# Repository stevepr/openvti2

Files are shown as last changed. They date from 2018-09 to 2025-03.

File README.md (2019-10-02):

# OpenVTI 2
----------------------------
The OpenVTI project implements a GPS based video time inserter for overlaying an accurate time stamp on each field of an analog video signal.  The OpenVTI device is an Arduino Mega 2560 single board computer along with a GPS receiver and a video overlay board.  This repository holds the Arduino source code.

## Building the OpenVTI software
---------------------------------
Prerequisites:
- Arduino IDE

## Building the OpenVTI hardware
------------------
The hardware:
- Arduino Mega 2560
- Gowoops GPS Module U-blox NEO-6M(Amazon: https://www.amazon.com/Gowoops-Module-Antenna-Arduino-Microcomputer/dp/B01MRNN3YZ)
- TinySine Video Overlay Shield using Max-7456

The source file pinconfig.h explains how to connect the GPS module and the TinySine board.

## Licensing
------------
 This program is free software: you can redistribute it and/or modify it under the terms of the GNU General Public License as published by the Free Software Foundation, either version 3 of the License, or (at your option) any later version.

 This program is distributed in the hope that it will be useful, but WITHOUT ANY WARRANTY; without even the implied warranty of MERCHANTABILITY or FITNESS FOR A PARTICULAR PURPOSE.  See the GNU General Public License for more details.

## Developers & Contributors
----------------------------
- Michael Fulbright
- Steve Preston

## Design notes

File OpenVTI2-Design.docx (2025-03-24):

# OpenVTI2 Design Document

Steve Preston (2025 Mar 24)

# 1 Overview

The OpenVTI project was initiated by Michael Fulbright in early 2017. The OpenVTI project provides both hardware guidelines and code for building a GPS based VTI (video time inserter) using an Arduino “platform”. This document describes OpenVTI2 - a “fork” in the design for the OpenVTI project.

The OpenVTI devices shared a single primary goal of overlaying an analog video signal with information which can be used to establish an accurate time, based on UTC (Coordinated Universal Time), for the VSYNC pulse at the start of each field in the analog video signal. In this sense, they are not different from the IOTA-VTI. The IOTA-VTI has a long history as an accurate, and successful VTI. The OpenVTI differs from the IOTA-VTI via simpler construction and, importantly, a simpler approach to the time stamp information. The IOTA-VTI is designed to both identify and correct many types of aberrant behaviors with the GPS receiver and the video signal. The OpenVTI is designed to merely detect and “flag” these errors (not correct the errors). In addition, the IOTA-VTI is a retail product that includes some level or service and support. And, the OpenVTI project is a DIY (Do It Yourself) effort with no support beyond the limited documentation provided with the code.

The OpenVTI2 design differs from the OpenVTI design in that it requires an Arduino Mega2560 instead of the less expensive Arduino Uno. In addition to the Arduino Mega2560, OpenVTI2 includes a GPS receiver “breakout board” based on a Ublox GPS receiver chip and an OSD (On Screen Display) Arduino shield based on the Max7456 video overlay chip.

# 2 Features

This section documents the three two basic features of OpenVTI2: The Video Overlay, the GPS serial data output, and the Error Checking.

## 2.1 Video Overlay

OpenVTI2 overlays two lines of information at the bottom of each video field: An Upper Line and a Lower Line. There are five display modes for the overlay: Time Valid, Waiting for GPS, Syncing, Error, and Fail. OpenVTI2 starts with the Invalid mode overlay and switches to the Valid mode display only after some initial error checking. After the initial startup, OpenVTI2 will switch to Invalid Mode after detecting any errors and only switch back to Valid mode after all errors have “cleared”. There is more information on error detection and error handling in another section of this document below.

### 2.1.1 Time Valid Overlay

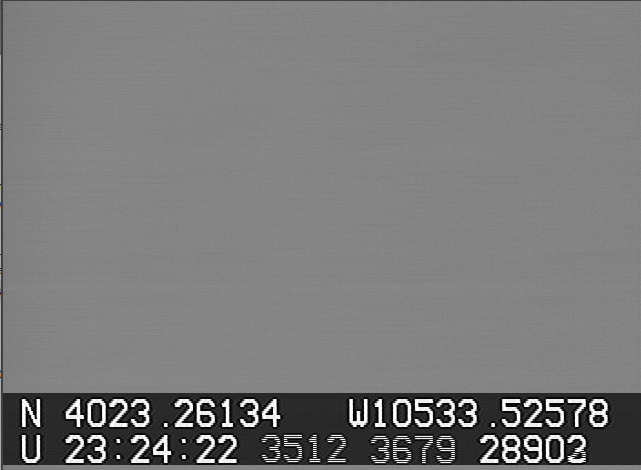
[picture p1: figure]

When OpenVTI2 has a valid time base it will use the Time Valid Overlay. In Time Valid mode, The Upper Line rotates through four different types of data type, changing data type once per second (at the arrival of the PPS signal from the GPS). Because the rotation of Upper Line data type occurs on a PPS and is not aligned with the arrival of the data sentences from the GPS receiver, some of these values may change during the one second interval for a data type. For example, the rotation for Lat/Long data may start with one value for Latitude and change to a different Latitude when it receives a new value from the GPS receiver prior to the end of the rotation period (next PPS).

- Date (UTC): This data type displays the date as DD-MM-YYYY
- Lat/Long: This data type displays the Latitude and Longitude.
- Altitude: This data type displays the MSL Altitude, units for the altitude, the geoid separation ( N ) , and the Datum for the Altitude.
- Version/UTC Offset: This data type displays a version number for the OpenVTI2 software and displays the current GPS-UTC time offset from the GPS Receiver. The UTC Offset value has a prefix of “D” when the GPS receiver is using the default value from the firmware. When the GPS receiver has acquired a new almanac (with a current UTC offset), there is no “D” postfix.

The Lower Line is divided into four “fixed” sections (no rotation):

- PPS Mark: Column 0 (first character) of the line will normally be blank but will change to a marker character during the first video field after a PPS from the GPS receiver.
- Time Base (G or U): Column 1 of the line will be “U” when the time displayed is UTC time and will be “G” when the time displayed is GPS time. OpenVTI2 displays GPS time when the GPS receiver is using the firmware default value for the GPS-UTC time offset.
- Time (HH:MM:SS) : Column 3 through 10 will be the HH:MM:SS part of the time stamp for the VSYNC at the beginning of the current video field.
- Field 1 Time: Column 12 through 15 are the fractional seconds of the time stamp for field 1. This section is blank during field 2.
- Field 2 Time: Column 17 through 20 are the fractional seconds of the time stamp for field 2. This section is blank during field 1.
- Field Count: Column 22 through 28 are the total number of VSYNC pulses that have been seen since power up of the OpenVTI2 device. This count resets to zero after 9999999.

### 2.1.2 Waiting for GPS Mode Overlay

After power-up, or after an error, OpenVTI2 will not have a valid time base and will start looking for valid data inputs from the GPS to begin synchronizing with the GPS time signals. During this timeframe OpenVTI2 will be in “Waiting for GPS” mode. In this mode, the video overlay will display an Upper Line and a Lower Line as follows.

The Upper Line has three data sections:

- Last PPS time: timer tick count of the last PPS pulse.
- Field 1 VSYNC time: When overlaying field 1 of the video signal, this section contains the OpenVTI2 timer tick count, in hex format, for the VSYNC at the start of field 1. Otherwise, this section is blank. This section starts with column 1.
- Field 2 VSYNC time: When overlaying field 2, this section contains the timer tick count for the VSYNC at the start of field 2. This section starts with column 15.

The Lower Line has two sections:

- Status Message: The message “Waiting for GPS” will appear starting in Column 1
- Field Count: Column 22 through 28 are the total number of VSYNC pulses that have been seen since power up of the OpenVTI2 device. This count resets to zero after 9999999.

### 2.1.3 Syncing Mode Overlay

After establishing valid GPS data communication (both NEMA sentences and PPS must be valid), OpenVTI2 will start the process of synchronizing the internal timer counts with the GPS inputs. This process should last approximate 5 seconds. In this mode, the video overlay will display an Upper Line and a Lower Line as follows.

The Upper Line has three data sections:

- Last PPS time: timer tick count of the last PPS pulse.
- Field 1 VSYNC time: When overlaying field 1 of the video signal, this section contains the OpenVTI2 timer tick count, in hex format, for the VSYNC at the start of field 1. Otherwise, this section is blank. This section starts with column 1.
- Field 2 VSYNC time: When overlaying field 2, this section contains the timer tick count for the VSYNC at the start of field 2. This section starts with column 15.

The Lower Line has two sections:

- Status Message: Starting in Column 1, the message “Sync” followed by the number of seconds remaining for the sync process.
- Field Count: Column 22 through 28 are the total number of VSYNC pulses that have been seen since power up of the OpenVTI2 device. This count resets to zero after 9999999.

### 2.1.4 Error Mode Overlay

OpenVTI2 enters Error mode if it detects a recoverable error during operation. In this mode, OpenVTI2 will display an error message for two seconds, then move to “Waiting for GPS” mode to try to re-establish a time base. In Error mode, the video overlay will display an Upper Line and a Lower Line as follows.

The Upper Line has three data sections:

- Last PPS time: timer tick count of the last PPS pulse.
- Field 1 VSYNC time: When overlaying field 1 of the video signal, this section contains the OpenVTI2 timer tick count, in hex format, for the VSYNC at the start of field 1. Otherwise, this section is blank. This section starts with column 1.
- Field 2 VSYNC time: When overlaying field 2, this section contains the timer tick count for the VSYNC at the start of field 2. This section starts with column 15.

The Lower Line has two sections:

- Status Message: Starting in Column 1, a message describing the error condition.
- Field Count: Column 22 through 28 are the total number of VSYNC pulses that have been seen since power up of the OpenVTI2 device. This count resets to zero after 9999999.

### 2.1.5 Failure Mode Overlay

OpenVTI2 enters Failure mode if it detects an Unrecoverable error during operation. In this mode, OpenVTI2 will display an error message on one line (the Lower line position). You must power cycle the device to exit Failure mode.

Currently, OpenVTI2 will enter failure mode only if it cannot initialize the GPS receiver.

## 2.2 GPS Serial Data Output

After power-up OpenVTI2 will output the GPS serial data stream (NMEA and PUBX sentences) to the Arduino’s USB port. The OpenVTI2 will send this data at a baud rate of 115200 baud. In addition to the NMEA and PUBX sentences, OpenVTI2 will also output a “time marker sentence” with 100 microseconds of the PPS signal from the GPS receiver and the VSYNC pulses on the video input signal. This following list describes the sentences output to the Arduino’s USB port.

- GPS Sentences: The GPS receiver outputs a stream of data sentences over the serial port to the Arduino. OpenVTI2 will echo these GPS sentences to the Arduino USB port one character at a time (as the characters are received from the GPS receiver). The following list is an example of the typical GPS sentences that will appear on the USB port.
  - $GPRMC
  - $GPGGA
  - $GPDTM
  - $PUBX,04 (proprietary sentence defined by Ublox. See the Ublox documentation for details)
- <P>TTTTTTTT</P>: marks the occurrence of the PPS signal from the GPS receiver. TTTTTTTT is the count from the internal timer of the Arduino (in hex format) at the time of the PPS. This output is sent as soon as possible after the occurrence of the PPS. Note: the internal timer is running at approximately 2mhz.
- <V>TTTTTTTT</V>: marks the occurrence of a VSYNC pulse in the video signal with the timer count for the VSYNC pulse. This output is sent as soon as possible after the occurrence of the VSYNC pulse.
- NOTE: the PPS and VSYNC outputs are send “immediately” from interrupt routines and may “interrupt” the output of a GPS sentence or a PPS/VSYNC output (thus appearing in the “middle” of another GPS sentence output to the USB port).

## 2.3 Error Checking

Perhaps “error checking” should be listed as a requirement rather than a feature, but this seemed like a reasonable part of the document to specify the error checks performed by the OpenVTI2 code.

The Arduino processor in OpenVTI2 examines inputs from two different sources to determine the timing of the input video signal: the GPS receiver and the Max7456 OSD chip. The GPS receiver provides basic time, position, and status information via sentences sent across a serial port connection to the Arduino. The GPS also outputs a “digital” PPS signal to the Arduino which marks the exact start of the UTC second. The Max7456 OSD chip outputs “digital” signals for both VSYNC and HSYNC pulses detected on the input analog video signal. The OpenVTI2 code performs validation checks on these inputs as described below.

### 2.3.1 Initialization of GPS Receiver

At power-up OpenVTI2 attempts to initialize the GPS receiver to a specific state by sending command across the serial port to the GPS receiver. The OpenVTI2 code expects an “ack” response to each initialization command sent to the GPS receiver. If the GPS receiver fails to send a valid “ack” response to any command, OpenVTI2 reports a “GPS Initialization failure” and enters Failure mode (non-recoverable error).

### 2.3.2 Validation of GPS Sentences

After receiving a full NMEA sentence from the GPS receiver, OpenVTI2 will parse the sentence to decode and validate the information in the sentence. OpenVTI2 checks various values for time and position. If OpenVTI2 finds an error when parsing a sentence, it will enter Error Mode, then move to “Waiting on Sync” to try to recapture synchronization with the GPS time base.

### 2.3.3 Validation of PPS signal from GPS Receiver

OpenVTI2 uses an internal timer, running at approximately 2mhz, on the Arduino processor as an internal time base. On each PPS signal from the GPS receiver, OpenVTI2 checks the delay from the previous PPS signal to ensure that the time between the two PPS signals was within a reasonable tolerance of a 1 second delay. If this test fails, OpenVTI2 enters Error Mode (to report the error), then moves to “Waiting on Sync” mode to begin the process of trying to recapture synchronization with the GPS time base.

OpenVTI2 also validates the correlation between the UT seconds reported in the NMEA sentences and the number of PPS signals received from the GPS receiver. The GPS receiver should send out a full set of NMEA sentences after every PPS signal. The NEMA data after each PPS signal provides the time of the preceding PPS signal. During the “Syncing” mode, OpenVTI2 will use the NMEA data to establish the time (in whole seconds) corresponding to each second. During Time Valid mode, after Syncing, OpenVTI2 will “know” the time corresponding to each PPS. At each NMEA time sentence, OpenVTI2 will verify the time from the latest NMEA sentence against the internal “PPS time”. If this test fails, OpenVTI2 will enter Error Mode (then attempts to re-sync).

### 2.3.4 Validating VSYNC input

The VSYNC signal is part of the video input and not actually used to establish the internal time base of OpenVTI2. However, the VSYNC signal generates an interrupt 50 or 60 times per second (NTSC or PAL video) and therefore provides a frequent opportunity to validate the timing of the PPS signal. At every VSYNC interrupt, OpenVTI2 checks the time delay since the last PPS signal. If the delay since the last PPS signal is significantly greater than 1 second, the GPS receiver has “missed” a PPS signal. If this error occurs, OpenVTI2 enters Error Mode (then attempts to re-sync).

# 3 Components/Build

OpenVTI2 comprises three main components: an Arduino Mega 2560 R3 board, a GPS receiver board based on a Ublox GPS receiver, and a Max7456 overlay “Arduino shield” from TinySine. Building the OpenVTI2 requires some additional pieces, and a small bit of soldering. This section provides more details on the parts and steps for building the OpenVTI.

Components/Build notes:

- Arduino Mega2560 R3
  - https://a.co/d/6sFUShn
- TinySine OSD shield
  - OSD Shield for Arduino - On Screen Display (https://www.tinyosshop.com/arduino-osd-shield)
  - Solder 1x3 or 1x4 Header for hsync/vsync/los jumper connection: Arduino Stackable Header(8Pin) (https://www.tinyosshop.com/index.php?route=product/product&path=63_80&product_id=80)
    - Cut this in half and use either a 4 pin and a 3 pin header
    - *** NOTE these headers have extra long pins. Order the 1x8 from TinySine to make sure the length matches the rest of the headers on the TinySine OSD board.
- OpenVTI Shield

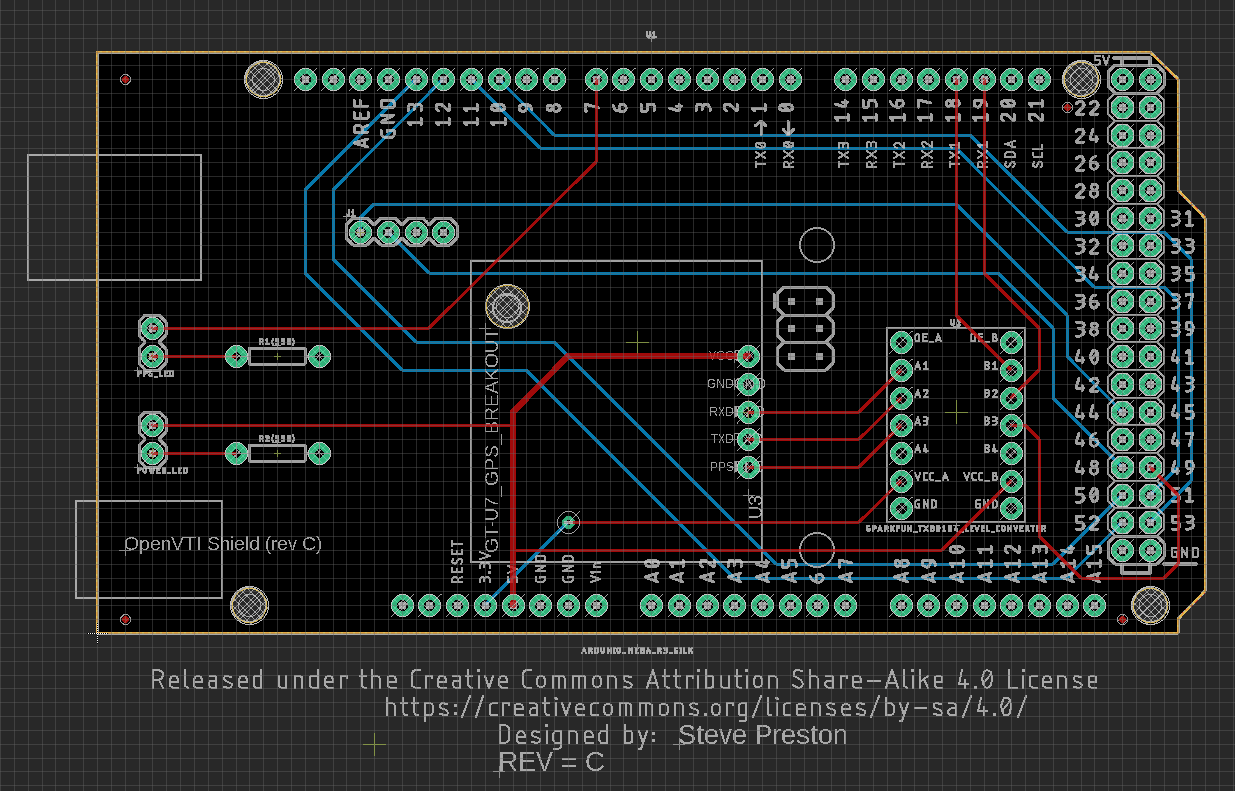
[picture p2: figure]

  - Order PCB using the Eagle file. I have always used OSHPark.
  - Solder Arduino Mega headers to the shield PCB
    - Header Kit from Amazon: https://a.co/d/1AGSMS7
  - Solder jumper for OSD connection
    - J1 (OSD) header - 1x4 female header. Note that a non-stacking female header is probably best.
  - Solder on LEDs
    - (2) Right angle: WP1533BQ/ID Kingbright | Optoelectronics | DigiKey (https://www.digikey.com/en/products/detail/kingbright/WP1533BQ-ID/2704754)
  - Breakout boards
    - Ublox GT-U7 GPS receiver: https://a.co/d/6Oyh4fR (2 pack)
      - Solder (1) 1x5 male header (GPS board usually includes this)
      - Solder breakout board to openVTI shield
      - Connect uFL to SMA cable to GPS board and anchor with a small zip tie
        - GPS Antenna + uFL to SMA cable https://a.co/d/1KBJGJA
    - TXB0104 level shifter: SparkFun Voltage-Level Translator Breakout - TXB0104 (https://www.sparkfun.com/sparkfun-voltage-level-translator-breakout-txb0104.html)
      - (2) 1x7 male headers. Probably best to add these headers to the txb0104 breakout before soldering onto the shield. Might help to have a "jig" for adding these headers to the breakout board.
      - Solder TXB0104 board to openVTI shield
  - Passive components
    - Solder (2) 330 ohm resistors to OpenVTI shield
- Final Assembly
  - Attach openVTI shield to Arduino Mega
  - Attach TinySine OSD shield on top of openVTI shield

Program

- Bring up the code with the Arduino IDE
- Set the Board type to Arduino Mega
- Set the Processor to AT Mega2560
- Set the Port (COMx)
- Sketch/Upload command to program the Arduino

# 4 Software Design Notes

## 4.1 Timing Strategy

OpenVTI2 uses the PPS signal from the GPS receiver as the only “time standard”. OpenVTI2 does NOT attempt to synchronize an internal timer with the PPS signal. Instead, OpenVTI2 validates PPS signals, tracks the HH:MM:SS time associated with each PPS, and generates a timestamp for each VSYNC of the video signal based on the delay from the most recent PPS signal.

OpenVT2 does use an internal timer to measure time delays: between occurrences of PPS and between a PPS and a VSYNC. The OpenVTI2 internal timer is set to a rate of approximately 2mhz. But OpenVTI2 constantly measures the average number of timer “ticks” for the interval between consecutive PPS signals and uses this value as the number of ticks/second for determining times.

## 4.2 Timer Config

OpenVTI2 uses two synchronized 16-bit timers.

## 4.3 General Interrupt configuration

The PPS and VSYNC inputs are key timing inputs to the system and both are connected to ICP inputs (input capture). The ICP input latches the time, timer count, of a signal within one processor clock cycle. A signal on the ICP line also generates an interrupt and transitions control to an ISR (Interrupt Service Routine) for the input signal. However, the ICP register avoids delays that can happen with when transitioning to an ISR (including delays due to other processing threads disabling interrupts). The ISR routine can read the ICP register to determine a very accurate time of the input signal regardless of the delay in transitioning to the ISR.

PPS is attached to the ICP register for Timer4 (ICP4) and VSYNC is attached to the ICP register for Timer5 (ICP5). These two timers are setup to be synchronized to the same exact time. Therefore ICP “times” for these two inputs are directly comparable.

Several internal variables are stored as “volatile”. Many of these variables are multi-byte quantities. When reading or writing a multi-byte volatile variable the code must be protected from interrupts. Otherwise an error might occur if an interrupt occurs while either reading or writing the variable.

## 4.4 Operating Modes (states)

There are six states for the device:

- Init – Startup and initialization of the GPS receiver and OSD board.
- WaitingForGPS – Waiting for valid PPS signals from the GPS receiver.
- Syncing – Synchronizing the internal second counts with the PPS and NMEA data from the GPS receiver.
- TimeValid – Current internal time is valid.
- Error – The device encountered and error and will try to restart.
- Fail – The device encountered an unrecoverable error.

## 4.5 PPS Interrupt Processing

The ISR routine for PPS interrupts has three primary purposes: validating the PPS signal, incrementing the HH:MM:SS second count for the current “system time”, and determining the main “state changes” in the system: from WaitingForGPS, to Syncing, to TimeValid. If this routine detects a PPS validation error during the Syncing or TimeValid mode, it transitions the system to ErrorMode.

## 4.6 VSYNC Interrupt Processing

The ISR routine for the VSYNC interrupt has one primary responsibility: updating the display. At each VSYNC, the ISR routine measure the time since the last PPS and updates the display. The information written to the display is dependent upon the current operating mode. In addition, the VSYNC ISR watches for missing PPS signals and moves to error mode if a PPS signal does not arrive in the expected timeframe.

## 4.7 Echo to USB port

OpenVTI2 echoes the NMEA sentences from the GPS receiver to the Arduino’s USB port. For these characters received over the serial port connected to the GPS receiver, OpenVTI2 echoes each character to the Arduino’s USB port as the character is received from the GPS receiver. OpenVT2 also sends a “marker” string to the USB port at each PPS from the GPS receiver. For the PPS markers, OpenVTI2 writes the PPS marker to the USB port from the PPS ISR. Similarly, OpenVTI2 sends a marker to the USB port for each VSYNC pulse (sent from the VSYNC ISR).

## 4.8 NMEA Parsing

OpenVTI2 reads the incoming serial port data from the GPS receiver via a polling loop in the system’s main process/routine. OpenVTI2 reads data from the serial port until it collects a single, complete NMEA sentence. After receiving a complete sentence, OpenVTI2 parses the data from the NMEA sentence and stores the data in an internal structure. After parsing a PUB04 sentence while in TimeValid mode, OpenVTI verifies that the HH:MM:SS fields from PUBX04 sentence matches the current internal HH:MM:SS count. If these values do not match, the system goes to Error Mode.

## 4.9 OSD Updates (Max7456 On Screen Display)

OpenVTI2 uses local memory arrays to store the data to be displayed in each row to overlay on the video signal. Both of the ISR routines and the main process loop may write data to these local memory arrays. But changes to the display will only update once per VSYNC pulse. At the end of each VSYNC ISR, OpenVTI2 writes the contents of the memory arrays to the Max7456 OSD chip.

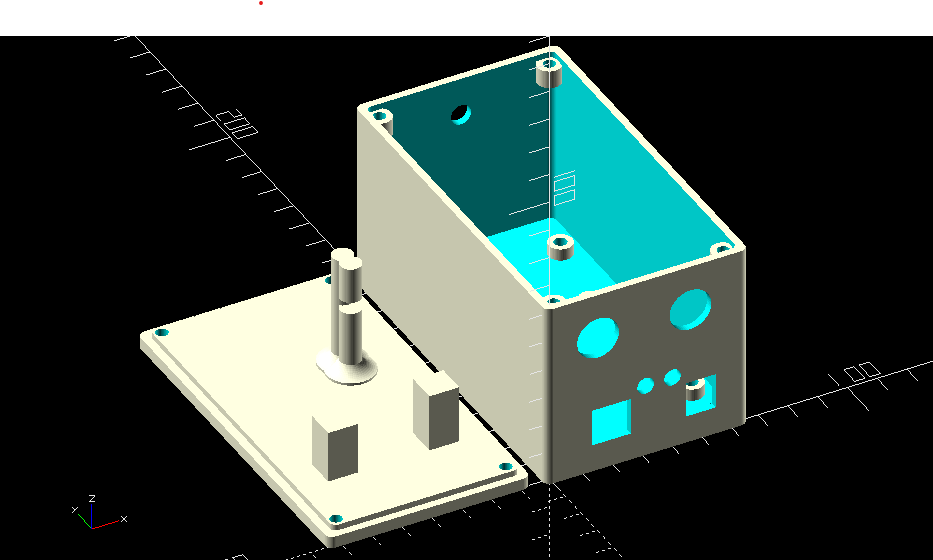
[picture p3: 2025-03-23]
enclosure/OpenVTI_Case_Image.png

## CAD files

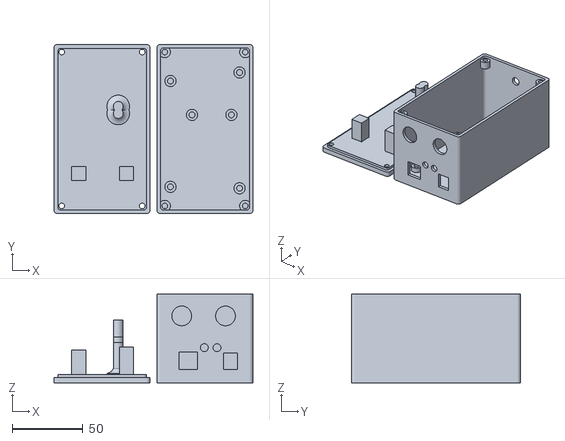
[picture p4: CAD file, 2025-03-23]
enclosure/Open_VTI_Case_Total.stl
141.0 x 120.0 x 63.0

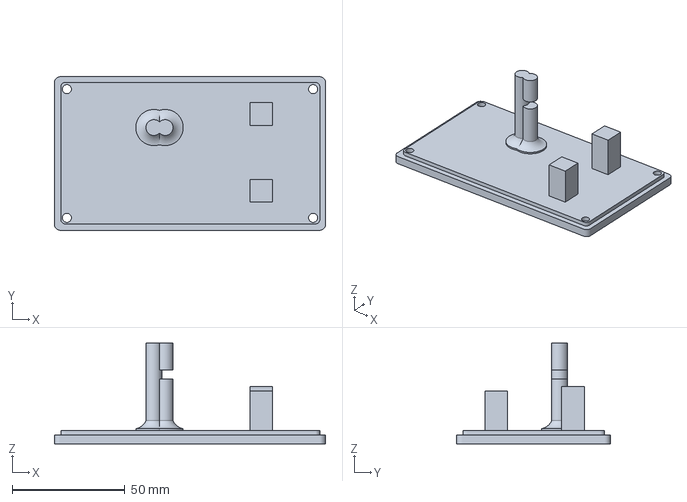
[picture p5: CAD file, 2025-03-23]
enclosure/Open_VTI_Case_lid_with_logo_qty_1.3mf
120.0 x 68.0 x 44.7 mm

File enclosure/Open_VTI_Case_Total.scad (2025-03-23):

//Mounting Pegs for Arduino Mega

// one complete peg

module peg(){

$fn=60;
    
difference(){
cylinder(7,d=8);
cylinder(8,d=4.2);
}

rotate_extrude()

    translate([2.5,0,0]){
    intersection(){
    square(5);
    difference(){
    square(5,true);
    translate([2.5,2.5])circle(2.5);    
            }  
        }
    }
}

module peg_placement(){

translate([2,16,0])
peg();

translate([2,91,0])
peg();

translate([51,15,0])
peg();

translate([51,97,0])
peg();

translate([17.3,67,0])
peg();
    
translate([45.2,67,0])
peg();

}

translate([5,0.5,0])
color("red")peg_placement();

$fn=60;
module case1(){
    minkowski(){
    cube([63,115,3]);
    cylinder(60,d=5);
    }
}

// Inner case for cutout

module case_inner(){
    minkowski(){
    cube([59,111,3]);
    cylinder(62,d=4);
    }
}

module case2(){
difference(){
case1();
translate([2,2,3])
color("blue")case_inner();
    }
}

//posts for lid

module case3(){
case2();
difference(){
translate([3,3,55])
color("red")cylinder(6,d=8);

translate([3,3,55])
color("green")cylinder(15,d=4);
}

difference(){
translate([3,112,55])
color("red")cylinder(6,d=8);

translate([3,112,55])
color("green")cylinder(15,d=4);
}

difference(){
translate([60,112,55])
color("red")cylinder(6,d=8);

translate([60,112,55])
color("green")cylinder(15,d=4);
}

difference(){
translate([60,3,55])
color("red")cylinder(6,d=8);

translate([60,3,55])
color("green")cylinder(15,d=4);
    }
}
// Lid

module lid1(){
translate([0,0,70]){
minkowski(){
    cube([63,115,2]);
    cylinder(2,d=5);
        }
    }
}
//translate([0,0,0])
//lid1();

module inner_lid(){
translate([2,2,68]){
minkowski(){
    cube([58.7,110.7,1]);
    cylinder(1,d=4);
        }
    }
}

//color("yellow")inner_lid();

module total_lid(){
    lid1();
    inner_lid();
}

module combined_lid(){
    lid1();
    inner_lid();
}

//punch holes in lid

module lid_with_holes(){
difference(){
combined_lid();

translate([3,3,63])
color("green")cylinder(15,d=4);

translate([3,112,63])
color("green")cylinder(15,d=4);

translate([60,112,63])
color("green")cylinder(15,d=4);

translate([60,3,63])
color("green")cylinder(15,d=4);
    }
}

translate([0,0,5])
rotate([0,180,0])

//lid with restraint

translate([10,0,-70])
lid_with_holes();

translate([-30,73.5,6.7])
color("blue")lid_restraint();

translate([-30,68.5,6.7])
color("blue")lid_restraint2();

module holes(){
//USB Hole
translate([16,-47,-0.6])
color("blue")cube([18,13,12.5
    ]);

//Power Hole
translate([16,-15.5,-0.6])
color("red")cube([19,10,12]);

//LED Holes
$fn=60;
rotate([0,90,0])
translate([-15,-29,15])
color("red")cylinder(20,d1=6,d2=5,true);

rotate([0,90,0])
translate([-15,-20,15])
color("red")cylinder(20,d1=6,d2=5,true);
    
    
//RCA Holes

rotate([0,90,0])
translate([-37.5,-45,10])
color("green")cylinder(30,d1=14,d2=14,true);

rotate([0,90,0])
translate([-37.5,-14,10])
color("green")cylinder(30,d1=14,d2=14,true);

// GPS SMA Hole

rotate([0,90,0])
translate([-40,-28,-99])
color("green")cylinder(10,d=6.8);

}

module case4(){
difference(){
case3();
translate([60,20,10])
rotate([0,0,270])
holes();
    }
}

case4();

// positioning nubs
/*
//right 
translate([57.6,88,1.8])
rotate([0,10,0])
color("red")cube([5,3,15]);

//left
translate([0.2,88,1.3])
rotate([0,-10,0])
color("red")cube([5,3,15]);

//rear

translate([29,101.6,2.3])
rotate([-10,0,0])
color("red")cube([3,13,16]);
*/
//clicker

module clicker(){
translate([0,0,-1])
cube([15,5,3],true);

rotate([10,0,0])
translate([-5,,0,8])
cube([5,2,20],true);

rotate([10,0,0])
translate([5,,0,8])
cube([5,2,20],true);


module click_stop(){

difference(){
translate([0,-4,12])
rotate([75,0,0])    
cube([15,8,4],true);
    
 translate([0,-4.6,9.3])
    rotate([10,0,0])
color("blue")cube([17,5,4],true);   

translate([0,0.4,15])
    rotate([12,0,0])
color("blue")cube([17,5,4],true);   
}
}
//translate([0,0,5])
//click_stop();
}

//translate([30.5,108,3])
//color("green")clicker();


// lid restraint


module lid_restraint(){

$fn=60;
    
cylinder(39,d=7);

rotate_extrude()

    translate([3,0,0]){
    intersection(){
    square(10);
    difference(){
    square(10,true);
    translate([6,7])circle(6);    
            }  
        }
    }
}

module lid_restraint2(){

$fn=60;

translate([0,0,27])
cylinder(12,d=7);
    
cylinder(23,d=7);

rotate_extrude()

    translate([3,0,0]){
    intersection(){
    square(10);
    difference(){
    square(10,true);
    translate([6,7])circle(6);    
            }  
        }
    }
}

translate([-29,21,6.5])
color("red")cube([10,10,20]);

translate([-63,21,6.5])
color("red")cube([10,10,18]);

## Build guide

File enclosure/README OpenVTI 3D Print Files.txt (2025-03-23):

OpenVTI 3D Print Files

File - OpenVTI_Case_Image.PNG - Case Image rendered using OpenSCAD
File - Open_VTI_Case_lid_with_logo_qty_1.3mf - File to print lid with logo
File - Open_VTI_Case_Total.scad - OpenSCAD case file
File - Open_VTI_Case_Total.stl - File to slice/print case 

Recommended filament - PETG.  Bambu Lab PETG-HF was used on BL X1-C printer
m3 brass inserts (7) - 3 for base (front left, front right, right rear), 4 for lid
m3 x 6mm screws (7)

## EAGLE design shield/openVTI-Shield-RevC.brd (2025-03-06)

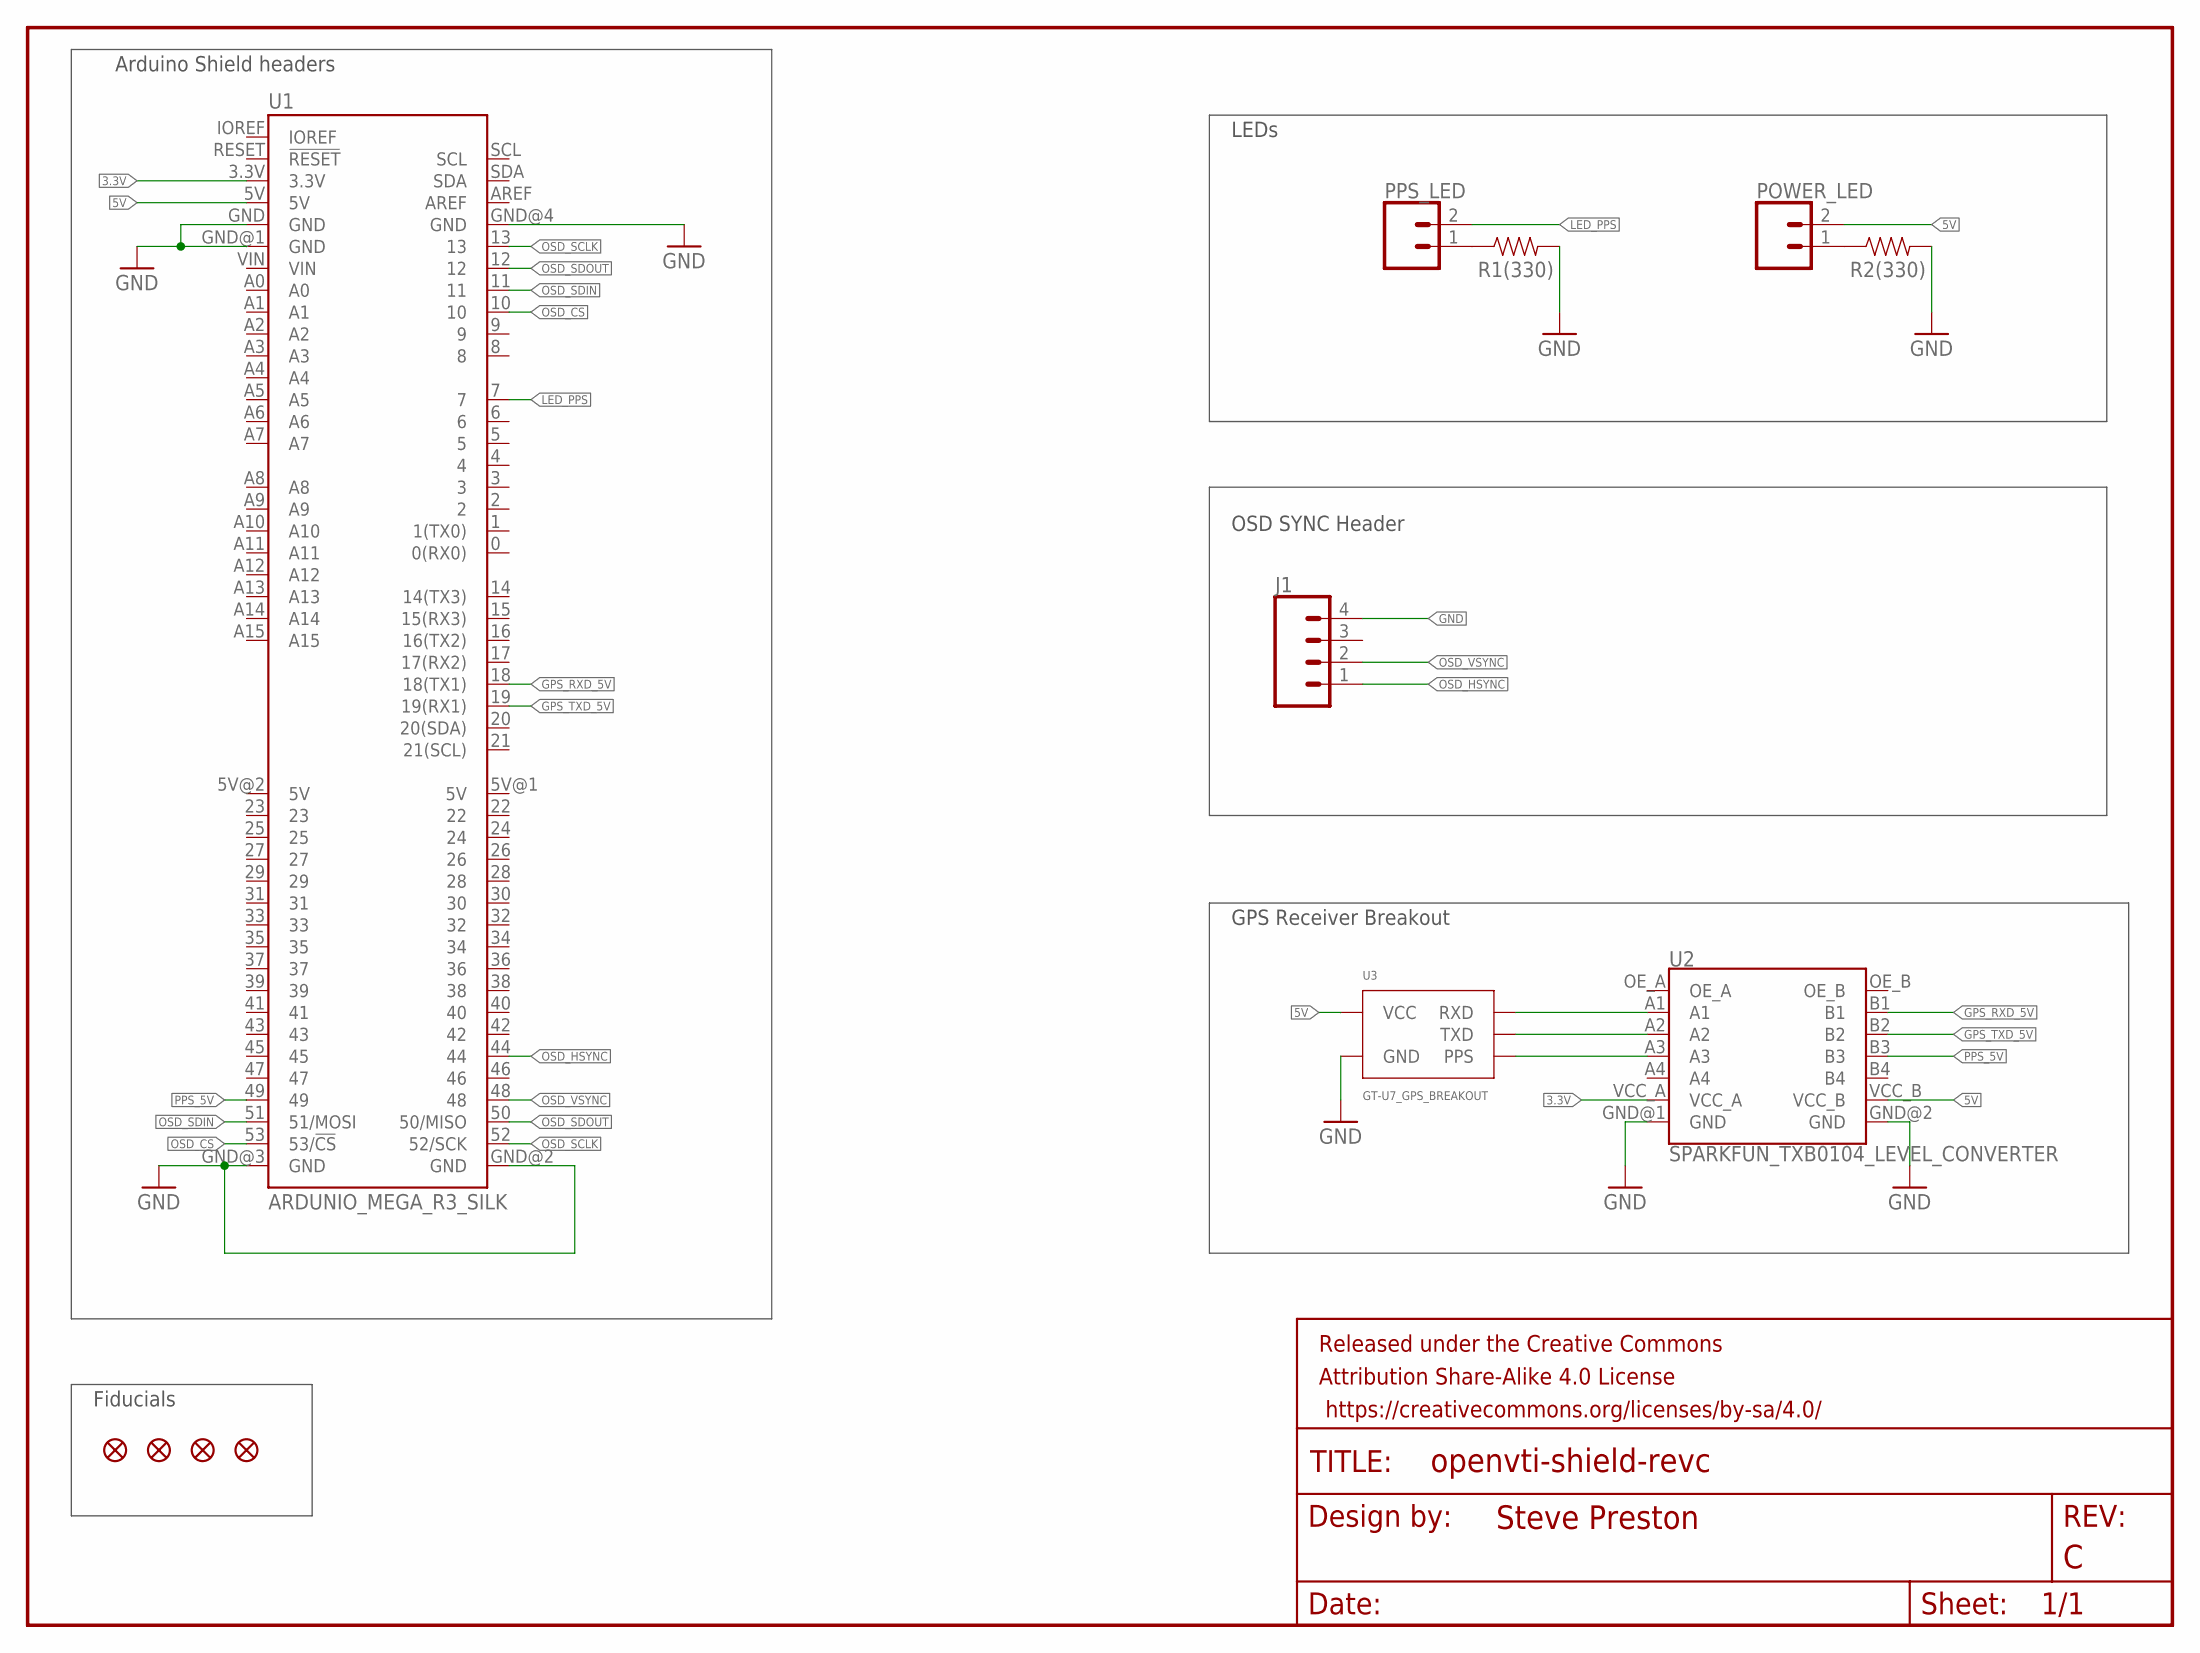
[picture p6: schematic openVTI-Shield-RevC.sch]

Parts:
FD1, FD2, FD3, FD4: FIDUCIALUFIDUCIAL; FIDUCIAL-MICRO
FRAME1: FRAME-LETTER; CREATIVE_COMMONS
J1: CONN_04PTH; 1X04
POWER_LED: CONN_02; 1X02
PPS_LED: CONN_02; 1X02
R1(330), R2(330): RESISTORAXIAL-0.3; AXIAL-0.3
U1: ARDUNIO_MEGA_R3_SILK; ARDUINO_MEGA_SILK
U2: SPARKFUN_TXB0104_LEVEL_CONVERTER; TXB0104_LEVEL_CONVERTER
U3: GT-U7_GPS_BREAKOUT; GT-UT

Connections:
3.3V: U1.3.3V, U2.VCC_A
5V: POWER_LED.2, U1.5V, U2.VCC_B, U3.VCC
GND: J1.4, R1(330).P$2 (2), R2(330).P$2 (2), U1.GND, U1.GND@1 (GND), U1.GND@2 (GND), U1.GND@3 (GND), U1.GND@4 (GND), U2.GND@1 (GND), U2.GND@2 (GND), U3.GND
GPS_RXD: U2.A1, U3.RXD
GPS_RXD_5V: U1.18 (18(TX1)), U2.B1
GPS_TXD: U2.A2, U3.TXD
GPS_TXD_5V: U1.19 (19(RX1)), U2.B2
LED_PPS: PPS_LED.2, U1.7
unnamed: PPS_LED.1, R1(330).P$1 (1)
unnamed: POWER_LED.1, R2(330).P$1 (1)
OSD_CS: U1.10, U1.53 (53/!CS)
OSD_HSYNC: J1.1, U1.44
OSD_SCLK: U1.13, U1.52 (52/SCK)
OSD_SDIN: U1.11, U1.51 (51/MOSI)
OSD_SDOUT: U1.12, U1.50 (50/MISO)
OSD_VSYNC: J1.2, U1.48
PPS: U2.A3, U3.PPS
PPS_5V: U1.49, U2.B3

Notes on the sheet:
LEDs
Arduino Shield headers
GPS Receiver Breakout
Fiducials
OSD SYNC Header

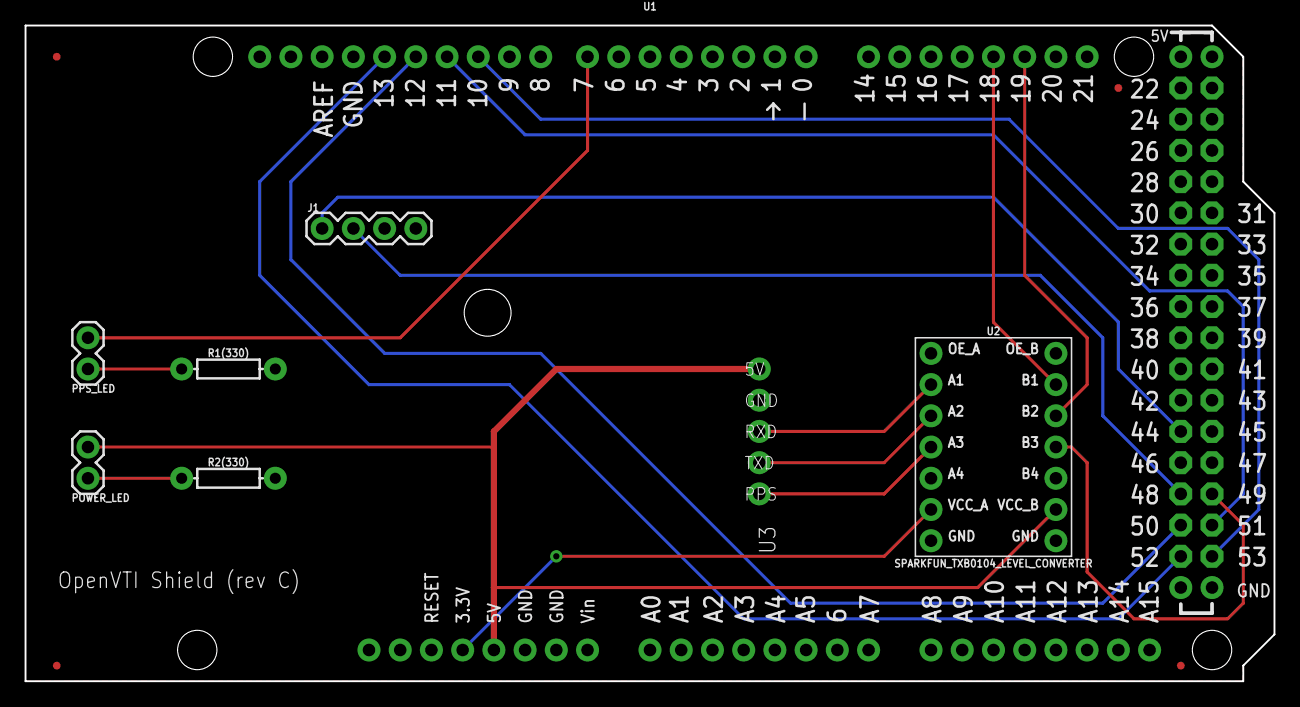
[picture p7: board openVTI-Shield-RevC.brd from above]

Board: 2 copper layers, 101.6 x 53.3 mm, 13 parts (0 on the bottom side), 18 nets.

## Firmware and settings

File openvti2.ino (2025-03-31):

/*

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
OpenVTI2

This is VERSION 6

ChangeLog

Version 1 
- initial using SoftwareSerial for GPS comms

Version 2 
- switch to HardwareSerial
- implemented field detection using VSYNC/HSYNC outputs from MAX7456 using external 555 or ATTINY13

Version 3
- use "arduino only" solution for field detection
- final version has working limovie time insertion

Version 4
- start with working limovie compatible time insertion
- move LED handler into VSYNC pin change interrupt handler
- make display more sparse to provide more area for stars!

Version 5
- SBP (from original OpenVTI code by MichaelF)
- interrupt driven PPS
- update OSD during vertical blanking
- write OSD update directly using auto-increment mode
- added code for parsing GPS serial data
- enabled  XXXX ublox proprietary sentence

Version 6
- moved to Mega2560 as required platform

VTI for following setup:

TinySine Video Overlay using Max-7456
Gowoops GPS Module U-blox NEO-6M
  (Amazon: https://www.amazon.com/Gowoops-Module-Antenna-Arduino-Microcomputer/dp/B01MRNN3YZ)

Use 5V power for GPS.

Use level converter for GPS signals to Arduino (TX,RX, and PPS)

Configure ublox GPS to the following:

- output GPGGA and PUBX,04 NMEA messages
- Timepulse set to UTC time (defaults to GPS)


LIBRARY NOTES:

I decided to start including library files in sketch directory - this way I can keep it self contained

MAX7456

I included zip files as well for original library
      
*/

// Included Libraries //////////////////////////////////////////////////////////

#include "pinconfig.h"
#include <SPI.h>
#include "MAX7456.h"
#include <util/crc16.h>

//  Global Settings ///////////////////////////////////////////////////////////////
#define VERSION  6

#define GRAYBACKGROUND 1    // == 1 => set gray background behind OSD lines
                            // == 0 => transparent background behind OSD lines


#define TESTROW 0           // == 1 => enable third row at top of display for testing/debug
                            // == 0 =>  no third row...

// Global Constants & Variables ////////////////////////////////////////////////////////////
//

// CRC data
//
uint32_t ProgramLength = 0x3000;
uint16_t pgmCRC = 0;

//*********************************
//  General state info
//
enum CountSource
{
  CNT4,
  CNT5,
  CR4,
  CR5
};

// Operating Modes
//
enum OperatingMode
{
  InitMode,               // => Power up initialization
  WaitingForGPS,          // => Waiting to receive valid GPS data
  Syncing,                // => Synchronizing internal time base with GPS data
  TimeValid,              // => Time is valid  (nominal operating mode for time insertion)
  ErrorMode,              // => Error was found
  FailMode                // => Unrecoverable failure found
};
volatile OperatingMode CurrentMode;    // Current operating mode
bool blnVideoIn = false;              // true iff video signal on input line
int errVideo = 0;


#define SYNC_SECONDS 10                // # of seconds for syncing to GPS time
volatile short int TimeSync;          // ( > 0 ) => we are syncing to GPS sentence times = # of seconds remaining for sync (small value so no problem with ints)

volatile int ErrorCountdown;
#define ERROR_DISPLAY_SECONDS 2

// Version message
//
char msgVersion[] = "6.4";
#define len_msgVersion 4

// Error Messsages
//
char msgGPSfail[] ="GPS init failed";
#define len_msgGPSfail  15
char msgWaiting[] = "Waiting for GPS";
#define len_msgWaiting  15
char msgSync[] = "Sync ";         // space for remainder
#define len_msgSync  4
char msgNoPPS[] = "*PPS ERROR*";
#define len_msgNoPPS 11
char msgSyncFailed[] = "*Sync FAILED*";
#define len_msgSyncFailed 13
char msgUnknownError[] = "*FATAL ERROR*";
#define len_msgUnknownError 13
char msgNoVSYNC[] = "*No VSYNC*";
#define len_msgNoVSYNC 13

char msgErrorCodes[] = "   ";
#define len_msgErrorCodes 3

// Sync Errors
//  1 = neither RMC nor PUBX04 is good
//  2 = RMC seconds does not match internal time
//  3 = RMC mode delay is neither A nor D
//  4 = RMC time delay != PPS time
//  5 = PUBX04 time != PPS time
//  6 = error transitioning from GPS time to UTC time


// Command string from the PC
//
#define CommandSize 30            // max size of a command string 
char strCommand[ CommandSize + 1 ];
int Cmd_Next;                     // speed optimization ( -1 => full command pending )

//***************
// OSD info
//
volatile bool EnableOverlay = false;      // update Overlay?
volatile bool blnSingleLineTest = false;  // true => display Bottom line ONLY in the TOP position (to allow another time stamp below).

// OSD object
//
MAX7456 OSD( osdChipSelect );

//  Local OSD rows
//
uint8_t TopRow[30];

uint8_t BottomRow[30];

#if (TESTROW == 1)
uint8_t TestRow[30];
#endif

// location of UI elements
//
#define TOP_ROW_NTSC 11
#define BOTTOM_ROW_NTSC  12
#define TOP_ROW_PAL 14
#define BOTTOM_ROW_PAL 15

#define FIELD1TS_COL 12
#define FIELD1TS_ROW BOTTOM_ROW

#define FIELD2TS_COL 17
#define FIELD2TS_ROW BOTTOM_ROW

#define FIELDTOT_COL 22
#define FIELDTOT_ROW BOTTOM_ROW
#define FIELDTOT_MAX 9999999        // max field count (row is only 29 char wide reliably)

volatile int osdTop_RowOffset = TOP_ROW_NTSC*30;   // display memory offset to start of ROW for cycling through data
volatile int osdTop_Col = 1;                       // starting colum in this ROW

volatile int osdBottom_RowOffset = BOTTOM_ROW_NTSC*30;   // display memory offset to start of ROW for time data
volatile int osdBottom_Col = 1;

// pixel offset of display to Match IOTA-VTI
//
#define OSD_X_OFFSET  0
#define OSD_Y_OFFSET  0

//
// Video input info
//
uint8_t videoStd;     // NTSC or PAL setting

volatile unsigned long fieldTotal;      // total number of fields (VSYNC pulses encountered)

volatile int fieldParity = 0;           // 1=> field 1, 2=> field 2  (0 => not yet set)

volatile unsigned long tk_VSYNC;      // vsync "time" = 2mhz ticks
volatile unsigned long tk_HSYNC;      // hsync "time" = 2mhz ticks

volatile unsigned short osdRotation = 0;             // rotation counter for top row (uses only one byte of short so we don't have to worry about interrupts)

//***********************
//  Time
//
volatile unsigned short timer4_ov;                            // timer 4 overflow count = high word of "time" (32ms per overflow)
volatile unsigned long Timer_Second = 2000000;                // # of ticks for 1 second
volatile unsigned long Timer_100ms = 200000;                  // ticks / 100ms
volatile unsigned long PPS_TOLERANCE = 2000;                  // tolerance for PPS interval - 1ms
volatile unsigned long CLOCK_TOLERANCE = 20000;               // tolerance for arduino clock frequency interval - currently 10ms


volatile unsigned long tk_pps_interval_total=0;         // sum of pps intervals
volatile unsigned long tk_pps_interval_count=0;         // # of pps interval
volatile unsigned long tk_pps_interval_ave=0;           // average pps interval

// YY-MM-DD HH:MM:SS time of current second
//   note: all values are less than 255 => don't need to protect individual changes from interrupts during read/write
//         HOWEVER ... the VSYNC ISR uses these values, so we should only update the groups of these variables with interrupts OFF
//
volatile bool time_UTC = false;         // true => time is currently UTC , false => time is currently GPS
volatile int sec_Year;                  // 2 digit
volatile int sec_Mon;
volatile int sec_Day;
volatile int sec_hh;
volatile int sec_mm;
volatile int sec_ss;
volatile int offsetUTC_Default = -1;      // receiver default value for GPS-UTC offset
volatile int offsetUTC_Current = -1;      // current/valid GPS-UTC offset

// LED control
//
int LED_PIN = 7;                                  // PIN for PPS LED output
volatile boolean LED_ON = false;                  // LED state
volatile unsigned short LED_Duration;             // # of clock counts for LED duration (16 us per tick)

//******************
// GPS info
// 
int gpsInitStatus;                        // GPS initialization status (0 => good)
const unsigned long gpsBaud = 9600;       

// PPS
//
volatile unsigned long tk_PPS;        // tick "time" of most recent PPS int
volatile unsigned long tk_PPS_valid;  // time of last VALID PPS int
volatile bool pps_now = false;        // true => PPS just happened
                                      
// GPS serial data
//

#define NMEA_MAX  201    // max length of a nmea sentence

uint8_t nmeaSentence[NMEA_MAX+1];     // current NMEA sentence
int nmeaCount = -1;                   // position of next char in NMEA sentence = # of chars in current sentence, 0 => no current sentence
  
#define MAX_FIELDS 17       // GGA has 17 fields (including the terminating CRLF)
int fieldStart[MAX_FIELDS];   // start position of each field
                              // end of field = (start of next field - 2)                         

volatile unsigned long tk_NMEAStart;
volatile int n_hh;
volatile int n_mm;
volatile int n_ss;
volatile bool n_blnUTC;
volatile unsigned long tk_GPSRMC;   // time (ticks) for start of current RMC data (if valid)
volatile unsigned long tk_PUBX04;   // time of start of current PUBX04 data (if valid)

volatile struct {
  bool valid;
  char mode;          // A or D => valid fix
  uint8_t hh;
  uint8_t mm;
  uint8_t ss;
  uint8_t yr;
  uint8_t mon;
  uint8_t day;
} gpsRMC;

#define MAX_LATLONG 12
#define MAX_ALT 10
struct {
  bool valid;
  uint8_t lat[MAX_LATLONG];     // latitude
  uint8_t NS;                   // North / South indicator for latitude
  uint8_t lng[MAX_LATLONG];     // longitude
  uint8_t EW;                   // East / West indicator for longitude
  uint8_t alt[MAX_ALT];         // MSL altitude
  uint8_t alt_len;              // length of alt field
  uint8_t alt_units;            // units for altitude (should be m for meters)
  uint8_t geoid_sep[MAX_ALT];   // geoid separation (N)
  uint8_t sep_units;            // units for geoid separation 
} gpsGGA;

struct {
  bool valid;
  uint8_t local_datum[3];
} gpsDTM;

struct {
  bool valid;
  uint8_t hh;
  uint8_t mm;
  uint8_t ss;
  uint8_t usLeapSec;      // current leap seconds
  bool  blnLeapValid;     // true => leap seconds is up to date, false => using firmware default value
  uint8_t cLeap[3];       // leap seconds field from sentence
} gpsPUBX04;

volatile bool blnEchoPPS = false;
char msgEchoPPS[] = "<P>TTTTTTTT</P>\n";
#define len_msgEchoPPS 16

volatile bool blnEchoVSYNC = false;
char msgEchoVSYNC[] = "<V>TTTTTTTT</V>\n";
#define len_msgEchoVSYNC 16

volatile bool blnEchoNMEA = true;
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
void loop() 
{

  // check video input
  //    We only check the video input UNTIL it first appears.  Afterwards the video is connected, we do not check again.
  //
  if (!blnVideoIn)
  {
    chkVideoInput();
  }

  // get & parse serial data from GPS
  //
  ReadGPS();

  // compute PPS stats
  //
  if ( tk_pps_interval_count == 10 )
  {
    noInterrupts();
    tk_pps_interval_ave = tk_pps_interval_total / tk_pps_interval_count;      // compute the average delay between PPS intervals
    Timer_Second = tk_pps_interval_ave;                                       // use this average as the new definition of a second
    Timer_100ms = Timer_Second / 10;
    
    tk_pps_interval_total = 0;                                                // reset
    tk_pps_interval_count = 0;
    interrupts();
  }

  // Read any pending command data from USB port
  //
  ReadCMD();

  // Execute pending command
  //
  if (Cmd_Next < 0)
  {
    
    ExecCMD();
  } // end of executing commands
    

} // end of loop()

//=====================================
//  ReadCMD - get pending command data from USB port
//    set CMD_Next = -1 when full command line available
//
//======================================
void ReadCMD()
{

  byte bIn;
  
  // read command from PC
  //  - one byte at a time
  //  - command terminates with a Newline char (\n)
  //
  while ( Serial.available() > 0 )
  {
    // was a command pending?
    //
    if (Cmd_Next < 0)
    {
      Cmd_Next = 0;     // not any more...
    }
    else if (Cmd_Next >= CommandSize)
    {
      // ran out of room => error
      //
      Cmd_Next = 0;   // reset to new command
    }
      
    // ok -> get the character & save it
    //   but don't save CR or LF
    //
    bIn = Serial.read();
      
    // if \n, terminate command line and don't save the \n
    //
    if (bIn == '\n')
    {
      strCommand[Cmd_Next] = 0;
      Cmd_Next = -1;
      break;
    }
    else if (bIn != '\r')
    {
      // here if NOT \r or \n
      //
      strCommand[ Cmd_Next ] = bIn;
      Cmd_Next++;
    }
    // if \r, do nothing with char
    
  } // end of loop reading incoming data
  
} // end of ReadCMD

//=====================================
//  ExecCMD - execute command from USB port
//
//======================================
void ExecCMD()
{
#if (TESTROW == 1)
      OSD.atomax(&TestRow[1], (uint8_t*)strCommand, 10);
#endif
  // parse the command and do it
  //  PPS ON => turn on PPS echo
  //  PPS OFF => turn off PPS echo (default)
  //  VSYNC ON => turn on VSYNC echo
  //  VSYNC OFF => turn off VSYNC echo (default)
  //  NMEA ON => echo NMEA sentences (default)
  //  NMEA OFF => do NOT echo NMEA sentences
  //  SLT ON => turn ON single line test mode
  //  SLT OFF => turn OFF single line test mode
  //
  if (strncmp(strCommand,"PPS ",4) == 0)
  {
    if (strncmp(strCommand + 4,"ON",2) == 0)
    {
      blnEchoPPS = true;
    }
    if (strncmp(strCommand + 4,"OFF",3) == 0)
    {
      blnEchoPPS = false;
    }
    // else ... do nothing
  }
  else if (strncmp(strCommand,"VSYNC ",6) == 0)
  {
    if (strncmp(strCommand + 6,"ON",2) == 0)
    {
      blnEchoVSYNC = true;
    }
    if (strncmp(strCommand + 6,"OFF",3) == 0)
    {
      blnEchoVSYNC = false;
    }
    // else ... do nothing
  }
  else if (strncmp(strCommand,"NMEA ",5) == 0)
  {
    if (strncmp(strCommand + 5,"ON",2) == 0)
    {
      blnEchoNMEA = true;
    }
    if (strncmp(strCommand + 5,"OFF",3) == 0)
    {
      blnEchoNMEA = false;
    }
    // else ... do nothing
  }
  else if (strncmp(strCommand,"SLT ",4) == 0)
  {
    if (strncmp(strCommand + 4,"ON",2) == 0)
    {
      blnSingleLineTest = true;
    }
    if (strncmp(strCommand + 4,"OFF",3) == 0)
    {
      blnSingleLineTest = false;
    }
    // else ... do nothing
  }
  // else ... didn't recognize the command ... do nothing

  // reset / clear command
  //
  Cmd_Next = 0;

  // all done
  //
  
} // end of ExecCMD

//=====================================
//  chkVideoInput()
//    check for video input
//    if video present, enable overlay
//    else (no video), disable overlay
//
//  NOTE:
//    OSD.lossOfSync() must not be called during other OSD operations. => protect it from interrupts
//
//======================================
void chkVideoInput()
{
  uint8_t rows;
  uint8_t cols;    
  bool blnLOS;


  // check for video input
  //
  noInterrupts();
  blnLOS = OSD.lossOfSync();
  interrupts();

  if (blnLOS)
  {

    errVideo = 1;

    // no Video Input => turn OFF overlay
    //
    blnVideoIn = false;
    EnableOverlay = false;
    OSD.noDisplay();        // turn off overlay

    return;

  }
  else
  {
    // YES, we have a video signal
    //  if OSD overlay already enabled, all done now
    //
    if (EnableOverlay)
    {
      errVideo = 2;
      return;
    }

    // set row and columns according to the video standard
    //
    videoStd = OSD.videoSystem();
    if ( videoStd == MAX7456_NTSC )
    {
      Serial.println("Video = NTSC");
      rows = OSD.safeVideoRows[MAX7456_NTSC][MAX7456_FULLSCREEN];
      cols = OSD.safeVideoCols[MAX7456_NTSC][MAX7456_FULLSCREEN];    
      OSD.setDefaultSystem(MAX7456_NTSC);
      
      osdTop_RowOffset = TOP_ROW_NTSC*30;    
      osdBottom_RowOffset = BOTTOM_ROW_NTSC*30;
    }
    else if (videoStd == MAX7456_PAL)
    {
      Serial.println("Video = PAL");
      rows = OSD.safeVideoRows[MAX7456_PAL][MAX7456_FULLSCREEN];
      cols = OSD.safeVideoCols[MAX7456_PAL][MAX7456_FULLSCREEN];    
      OSD.setDefaultSystem(MAX7456_PAL);
      
      osdTop_RowOffset = TOP_ROW_PAL*30;
      osdBottom_RowOffset = BOTTOM_ROW_PAL*30;
    }
    else
    {
      // unknown video standard => NO VIDEO INPUT
      //
      errVideo = 4;

      blnVideoIn = false;
      EnableOverlay = false;
      OSD.noDisplay();        // turn off overlay

      return;      // unknown video standard... do nothing
    }
    OSD.setTextArea(rows, cols, MAX7456_FULLSCREEN);
 
    OSD.setWhiteLevel(3);  // should be 0% black 80% white
    OSD.setCharEncoding(MAX7456_ASCII);       // use this char set

    // setup background for OSD area
    //
  #if (GRAYBACKGROUND != 1)
    OSD.videoBackground();
  #else
    OSD.setGrayLevel(4);
    OSD.home();                               //
    OSD.videoBackground();
    for ( int r = 0; r < rows; r++ )
    {
      for ( int c = 0; c < cols; c++ )
      {
        OSD.write((uint8_t)0);
      }
    }
    OSD.grayBackground();     // remaing writes will be gray background
  #endif

    // align with IOTA-VTI
    OSD.setTextOffset(OSD_X_OFFSET, OSD_Y_OFFSET);

    // we can move to WaitingForGPS now
    //
    CurrentMode = WaitingForGPS;
    
    // write message
    //
    for( int i = 0; i < FIELDTOT_COL; i++ )   // clear all but the field count
    {
      BottomRow[i] = 0x00;
    }   
    OSD.atomax(&BottomRow[1], (uint8_t*)msgWaiting, len_msgWaiting);

    // set display message (just to make sure)
    //
    OSD.sendArray(osdTop_RowOffset,TopRow,30);
    OSD.sendArray(osdBottom_RowOffset,BottomRow,30);  


    //*********************
    // enable VSYNC interrupt
    //
    TIMSK5 = (1 << ICIE5);                  // VSYNC timer 5: turn on IC interrupt for VSYNC and NO overflow interrupts

    //  VSYNC should be happening now
    //    let's check ... wait 100ms for a Vsync and field detect
    //
    
    delay(100);
    if (tk_VSYNC == 0)
    {
      errVideo = 3;
      // oops! No vsync coming in
      //   display error message and leave overlay OFF
      //
      Serial.println("*** NO VSYNC ***");    
      
      return;
    }

    // All good - video input now present
    //
    OSD.display();                              // Activate the text display.
    blnVideoIn = true;
    EnableOverlay = true;


  } // end of check for video input

}  // end of chkVideoInput

//*****************************************************************************************
// ISR routines
//*****************************************************************************************

//========================================
// ISR for LED done (timer 3 output compare A interrupt)
//=========================================
ISR(TIMER3_COMPA_vect)
{
  if (!LED_ON)
    return;
    
  // turn OFF LED
  //
  digitalWrite(LED_PIN,false);

  // turn OFF Timer 3
  //
  TCCR3B = (1 << WGM32);    // CTC set => mode 4 AND CS = 0 (no input => clock stopped)
  
} // end of LED_done_interrupt
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

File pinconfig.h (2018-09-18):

#ifndef PINCONFIG_H_
#define PINCONFIG_H_

// Pin Mapping /////////////////////////////////////////////////////////////////
  
  // pinValue = 0 means "not connected"

  //  FDTI Basic 5V                   ---  Arduino  VCC      (AVCC,VCC)
  //  FDTI Basic GND                  ---  Arduino  GND      (AGND,GND)
  //  FDTI Basic CTS                  ---  Arduino  GND      (AGND,GND)
  //  FDTI Basic DTR                  ---  Arduino  GRN
  //  FDTI Basic TXO                  ---> Arduino  0        [RXD, PD0]
  //  FDTI Basic RXI                 <---  Arduino  1        [TXD, PD1]
  
  
  //  Max7456 +5V   [DVDD,AVDD,PVDD]  ---  Arduino  VCC      (AVCC,VCC)
  //  Max7456 GND   [DGND,AGND,PGND]  ---  Arduino  GND      (AGND,GND)
  //  Max7456 CS    [~CS]            <---  Arduino  10  [PB2](SS/OC1B)
  //  Max7456 CS    [~CS]            <---  Mega2560 53  [PB0](SS/PCINT0)
  const byte osdChipSelect             =            53;
  
  //  Max7456 DIN   [SDIN]           <---  Arduino  11  [PB3](MOSI/OC2)
  //  Max7456 DIN   [SDIN]           <---  Mega2560 51  [PB2](MOSI)
  const byte masterOutSlaveIn          =            51;
  
  //  Max7456 DOUT  [SDOUT]           ---> Arduino  12  [PB4](MISO)
  //  Max7456 DOUT  [SDOUT]           ---> Mega2560 50  [PB3](MISO)
  const byte masterInSlaveOut          =            50;
  
  //  Max7456 SCK   [SCLK]           <---  Arduino  13  [PB5](SCK)
  //  Max7456 SCK   [SCLK]           <---  Mega2560 52  [PB1](SCK)
  const byte slaveClock                =            52;
  
  //  Max7456 RST   [~RESET]          ---  Arduino  RST      (RESET)
  const byte osdReset                  =            0;

  //  **********  need to solder connections for ~VSYNC and ~HSYNC
  //  Max7456 VSYNC [~VSYNC]         ---> Arduino   48   [ICP5]
  //  Max7456 HSYNC [~HSYNC]         ---> Arduino   44   [PL5]
  //  Max7456 LOS   [LOS]             -X-

  // GPS mapping

  // GPS VCC [3.3v]                  <---  Arduino  3.3V power
  // GPS GND                         <-->  Arduino  GND
  // GPS PPS [3.3v] [INPUT]          --->  Arduino  49   [ICP4] 
  //  
  // GPS TXD [3.3v]                  --->  Arduino  19   [RX1, PD2]
  // GPS RXD [3.3v]                  <---  Arduino  18   [TX1, PD3] 

/////////////////////////  defines for init and access /////////////////////////



  // VSYNC 
  //  connected to ICP for Timer 5 = ICP5
  //
#define VSYNC         48
#define VSYNC_PIN     PL1    
#define VSYNC_DDR     DDRL
#define VSYNC_PINR    PINL
#define VSYNC_CFG_INPUT() (VSYNC_DDR &= ~_BV(VSYNC_PIN))
#define VSYNC_READ() (VSYNC_PINR & _BV(VSYNC_PIN))

#define VSYNC_ISR() ISR(TIMER5_CAPT_vect)

  // HSYNC
  //  connected to digital pin 2 
  //
#define HSYNC       44
#define HSYNC_PIN   PL5       
#define HSYNC_DDR   DDRL
#define HSYNC_PINR  PINL
#define HSYNC_CFG_INPUT() (HSYNC_DDR &= ~_BV(HSYNC_PIN))
#define HSYNC_READ() (HSYNC_PINR & _BV(HSYNC_PIN))

  // PPS
  //  Connected to edge triggered ICP for Timer 4 = ICP4
  //
#define PPS         49
#define PPS_PIN     PL0       
#define PPS_DDR     DDRL
#define PPS_PINR    PINL
#define PPS_CFG_INPUT()   (PPS_DDR &= ~_BV(PPS_PIN))
#define PPS_READ()        (PPS_PINR & _BV(PPS_PIN))

#define PPS_ISR()           ISR(TIMER4_CAPT_vect)

#endif // PINCONFIG_H_

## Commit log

2017-10-27 PPS ticks
    Fixed bug with FieldParity (field 1 start lengthened to 20ms and =
    changed to ==)
    [openvti2.ino]
2017-10-28 PPS working
    pps finally works and matches IOTA VTI
    - fixed EICRA bit initialization
    [openvti2.ino, pinconfig.h]
2017-11-02 gps serial test 2
    fixed issues with init, removed hsync int
    [pinconfig.h]
2017-11-02 GPS serial test 2
    no readGPS & OSD.write
    no glitch after 40k fields...
    [MAX7456.cpp, MAX7456.h, openvti2.ino]
2017-11-02 test 3
    problem is sendArray - maybe too fast
    [MAX7456.cpp, MAX7456.h, openvti2.ino]
2017-11-02 Test 4
    writeArray seems to solve the issue. Might be timing.
    [MAX7456.cpp, MAX7456.h, openvti2.ino]
2017-11-02 another sendArray fix
    cleanup up logic for inAutoincrement and added write of 0xFF to actually
    turn if OFF after transferring array
    [MAX7456.cpp, openvti2.ino]
2017-11-04 Stability test 1
    lots of fixes. leaving in some optional code before cleanup. will run
    this version for an extended time to see if the display dies.
    [MAX7456.cpp, openvti2.ino]
2018-09-07 Clean up & bug fixes
    * re-organized state logic
    * fix some possible race conditions
    * add more error checking
    * clean-up
    * added documentation
    * added GPL header
    [MAX7456.cpp, MAX7456.h, openvti2.ino]
2018-09-07 GPS/UTC update fix
    fix logic for switching from GPS to UTC time
    [openvti2.ino]
2018-09-08 PUBX04 PPS test
    Added code to compare internal time to PUBX04 sentence and flag errors
    [openvti2.ino]
2018-09-13 Fixed precision of time stamp
    time stamp was rounding off too much with integer math. Now matches IOTA-VTI within 0.2ms
    [openvti2.ino]
2018-09-18 turn off testrow and one small fix
    [openvti2.ino, pinconfig.h]
2020-09-24 fixed error in checking time at 0hrs UT when based on GPS time
    [openvti2.ino]
2020-09-25 fixed overflow of int when checking PUBX time
    [openvti2.ino]
2020-10-03 various changes may have fixed the "glitch" via increasing the size of the gps sentence area by 1
    [openvti2.ino]
2020-10-04 Add PPS led
2021-01-29 added code to configure the time pulse (but still needs testing on the other breakout boards)
2025-03-06 Moved Video Input detection to Loop() routine to allow video to be added after power on of VTI
    [openVTI-Shield-RevC.brd, openVTI-Shield-RevC.sch]
2025-03-23 added 3d print files for enclosure
    [Open_VTI_Case_Total.scad, Open_VTI_Case_Total.stl, Open_VTI_Case_lid_with_logo_qty_1.3mf]
2025-03-30 lowered white level down to 80% to avoid affecting the intensity of the incomming video signal (per email from Bob Jones)
    [openvti2.ino]

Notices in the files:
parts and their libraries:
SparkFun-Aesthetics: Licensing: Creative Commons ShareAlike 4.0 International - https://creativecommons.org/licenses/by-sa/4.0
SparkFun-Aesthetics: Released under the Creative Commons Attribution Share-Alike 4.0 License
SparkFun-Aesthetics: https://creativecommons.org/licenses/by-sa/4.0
